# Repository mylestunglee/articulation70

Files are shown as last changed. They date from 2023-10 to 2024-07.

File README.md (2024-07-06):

# articulation70

The _articulation70_ keyboard is a successor to the [articulation80](https://github.com/mylestunglee/articulation80), with LEDs and a more personalised layout.

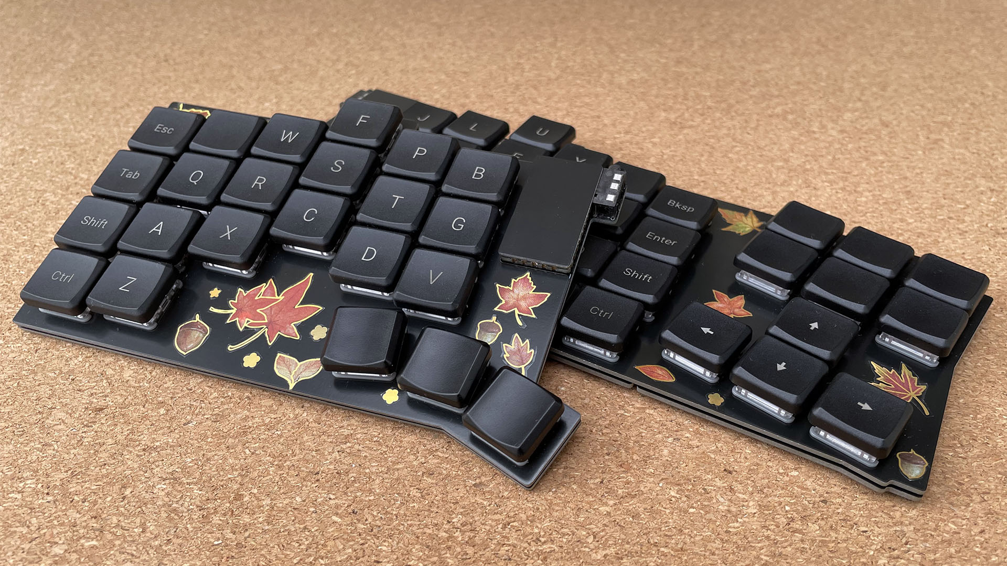
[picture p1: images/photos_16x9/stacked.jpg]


It features:
- Variable pinky stagger, supporting ±1 mm vertically offsetted soldering configurations.
- 3 × 6 main body, 3 thumb switches, 2 corner switches and 3 × 4 numpad layout.
- Kailh Choc V1 hot-swap support.
- A breakaway-able number pad.
- Serial or I2C connection between halves.
- Pro Micro-compatible controller support, however a micro-controller. with more pins are required to operate LEDs 2 and 3.
- 3 LEDs
- Reversible PCB to reduce manufacturing costs for hobby usage.

## KiCad plugins

This repo comes included with two plugins. To install these plugins, copy the directories in `plugins` into your _Plugins Directory_, which is found by _Tools → External Plugins → Open Plugins Directory_ in the PCB Editor.

### Split intersecting traces

When joining traces from rotated switches, it can be difficult to connect traces from two angles to form a aesthetic curve. This plugins splits two selected intersecting traces into four traces.

An example of use:

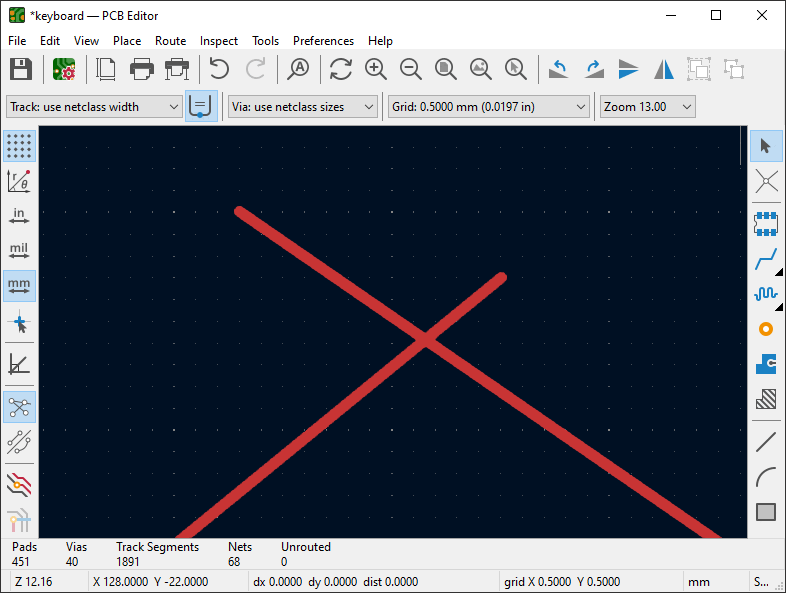
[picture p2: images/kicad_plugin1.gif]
KiCad plugin 1 animation


### Total trace length

Why not?

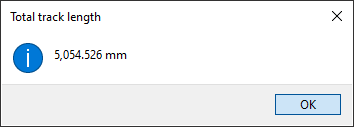
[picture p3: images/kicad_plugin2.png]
KiCad plugin 1


## Build Instructions

This build is very similar to many hobby keyboards. Please refer to the instructions for  [articulation80](https://github.com/mylestunglee/articulation80). You will need a soldering iron.

#### Which jumpers do I need to solder?

If using serial, then solder J1, and J4. If using I2C, then solder J2, J3 and J4. Solder on the back of each respective half.

### Build Parts

I would recommend substituting for cheaper or easier to source components when possible.

| Component | Quantity | MPN | Purchase Link | Remarks |
|:-|:-|:-|:-|:-|
| PCB | 2 |
| Left switch plate | 1
| Right switch plate | 1
| Micro-controller plate | 2
| Micro-controller | 2 | Elite-C | [Link](https://mechboards.co.uk/products/elite-c-v4)
| Through-hole TRRS jack | 2 | PJ-320A | [Link](https://mechboards.co.uk/products/trrs-jacks?variant=40330077241549)
| TRRS cable | 1 | | [Link](https://mou.sr/3QC5ykN) | Also called a 4-pin 3.5mm audio auxiliary cable |
| Reset button | 2 | PTS526 SM15 SMTR2 LFS | [Link](https://mou.sr/3tXtsOQ) | Different button operating force are possible
| LED | 3 | HLMP-1401 | [Link](https://mou.sr/45Zy9Vw) | Any T1 size
| 150Ω Resistor  | 3 | RC1206FR-07150RL | [Link](https://mou.sr/3QEyQzo) | Optional, for LEDs
| 4.7kΩ Resistor  | 2 | RC1206FR-104K7L | [Link](https://mou.sr/46XoOPE) | Optional, for I2C connection
| SMD Diode | 70* | 1N4148W-TP | [Link](https://mou.sr/3D01KSP) | Any SOD-123 size |
| Hot swap micro-controller sockets | 5 | 315-43-112-41-003000 | [Link](https://mou.sr/3QfEIO2) | Recommended
| Hot swap pins | 52 | 3320-0-00-15-00-00-03-0 | [Link](https://mou.sr/3tYd80f) | Recommended |
| Rubber feet | 12** | SJ-5302 CLEAR | [Link](https://mou.sr/3QFq1oL)
| Hot swap key sockets | 70* | CPG135001S30 | [Link](https://mechboards.co.uk/products/kailh-choc-hotswap-sockets)
| Key Switch | 70* | CPG135001 | [Link](https://www.aliexpress.com/item/1005005446722280.html)
| Key Cap | 70* | | | Ideally different key caps for thumbs |
| Stickers | 1 | | [Link](https://www.aliexpress.com/item/1005005222836654.html) | Optional

*Adjust for number of keys desired.

**Adjust for number of numpads.

## How to order PCBs and plates

I ordered from JLCPCB, however there are many other manufacturers. Take a look at [PCBShopper](https://pcbshopper.com/).

For the PCBs, I used:
- Base material: FR-4
- PCB thickness: 1.6 mm
- PCB colour: black
- Surface finish: LeadFree HASL
- Remove order number: Yes

For the switch plates, I used:
- Base material: FR-4
- PCB thickness: 1.2 mm
- PCB colour: black
- Surface finish: HASL (with lead) because the unleaded option greatly increases cost and the plates do not have any pads.
- Remove order number: Yes

For the controller plates, I used:
- Base material: FR-4
- PCB thickness: 1.2 mm
- PCB colour: black
- Surface finish: HASL (with lead)
- Remove order number: Yes

## How to adjust the layout

This was tested on installation of FreeCad 0.20.2, Python 3.11.6 and KiCad 7.0.6.

1. First, open `layout.FCStd` with FreeCad and open _Constants_ under the model tree view. You should see a spreadsheet of parameters.

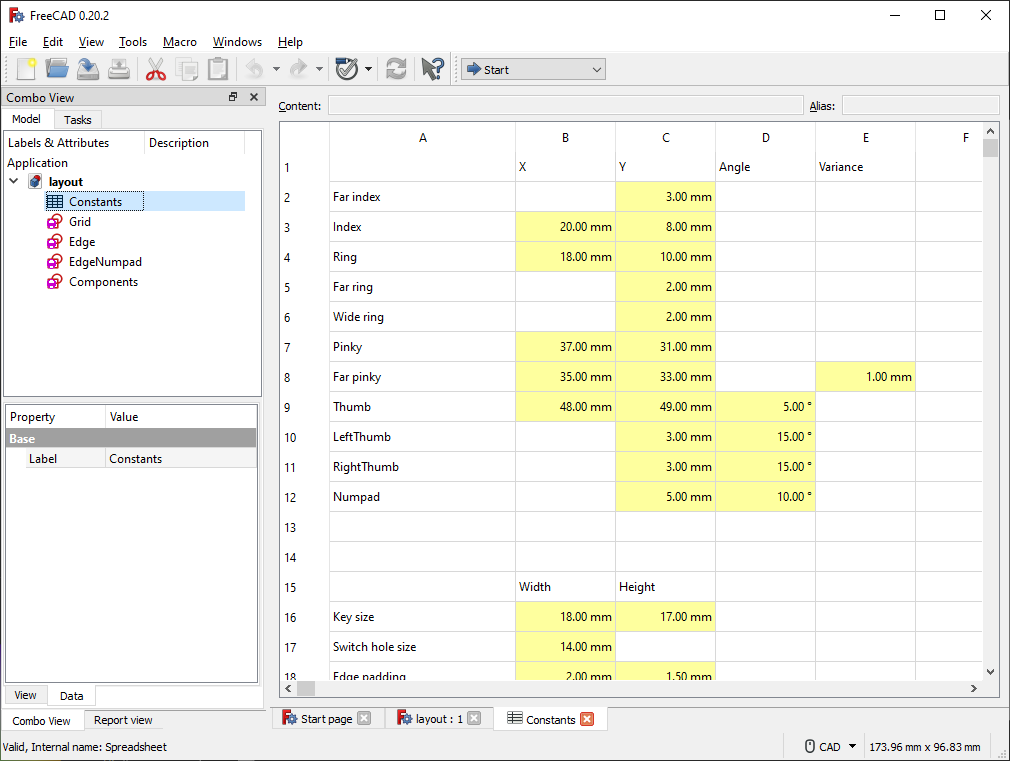
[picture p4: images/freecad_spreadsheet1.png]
FreeCad spreadsheet 1

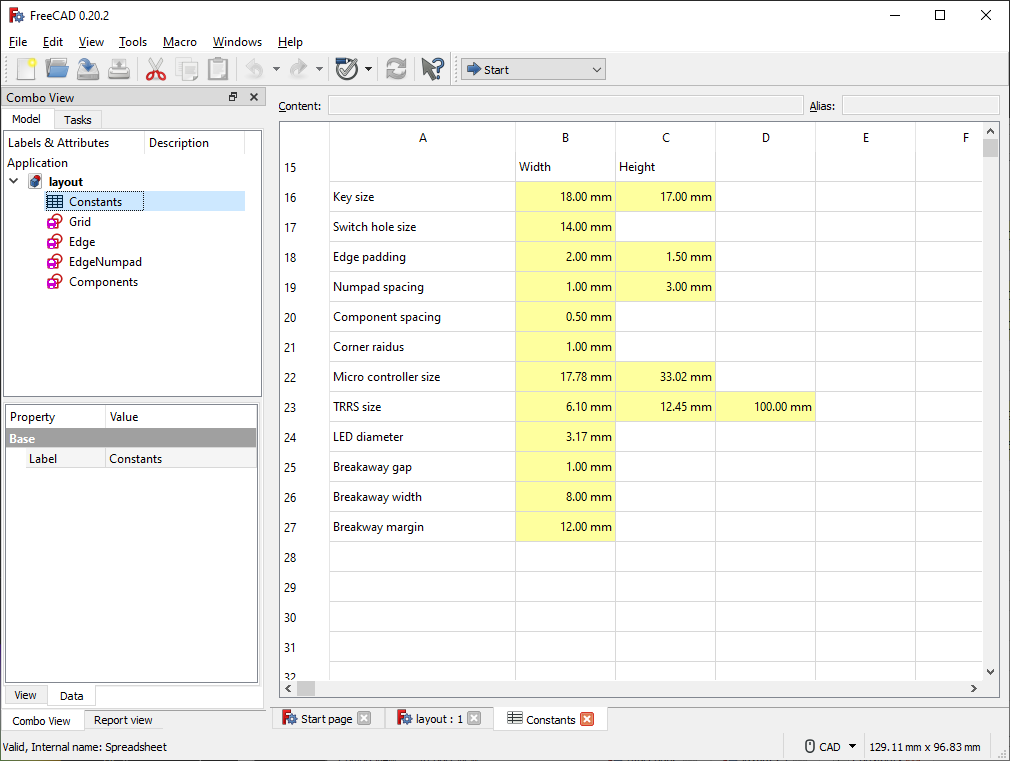
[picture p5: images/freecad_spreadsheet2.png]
FreeCad spreadsheet 2


2. Change values as necessary. If the values change too much from their intended range, then the sketch (as shown in the next step) may become broken.
3. Click on one of the sketches in the model tree view. Verify the layout shown is correct.

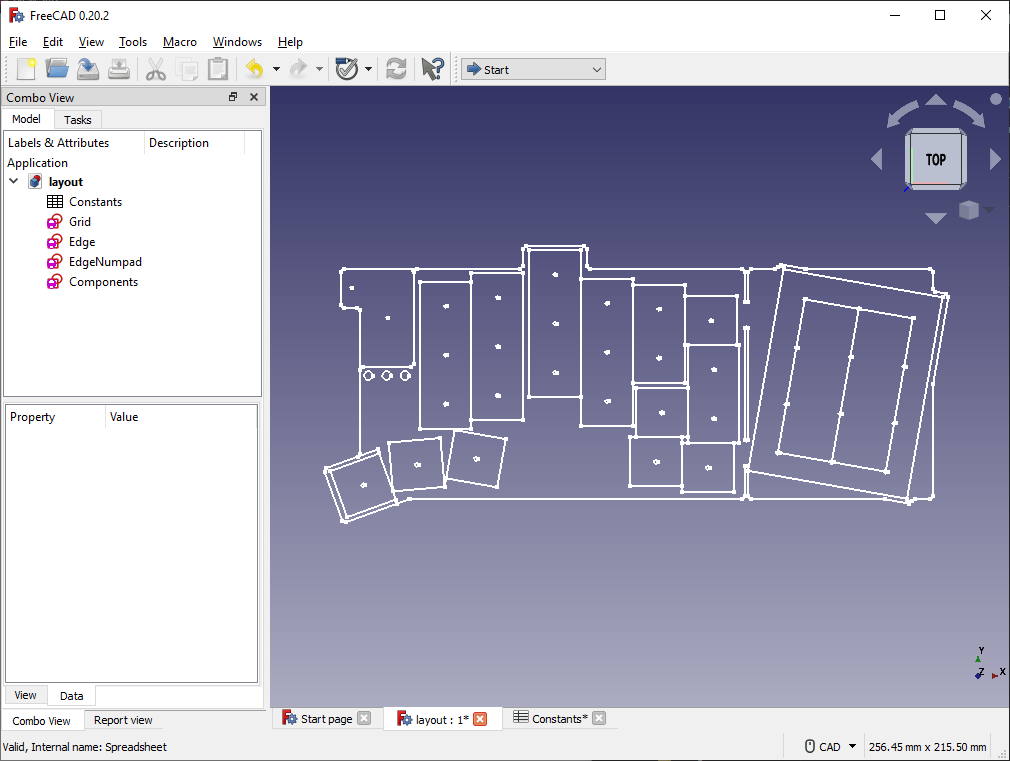
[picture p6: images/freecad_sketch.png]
FreeCad sketch


4. Export the layout to a file by coping the contents of `scripts/export_geometry.py` into FreeCad's Python console. The console is accessible by _View → Panel → Python console_. If you get a permission error, change `geometry.txt` to an absolute path within the repo. You should get a number, which reports the bytes written to `geometry.txt`.

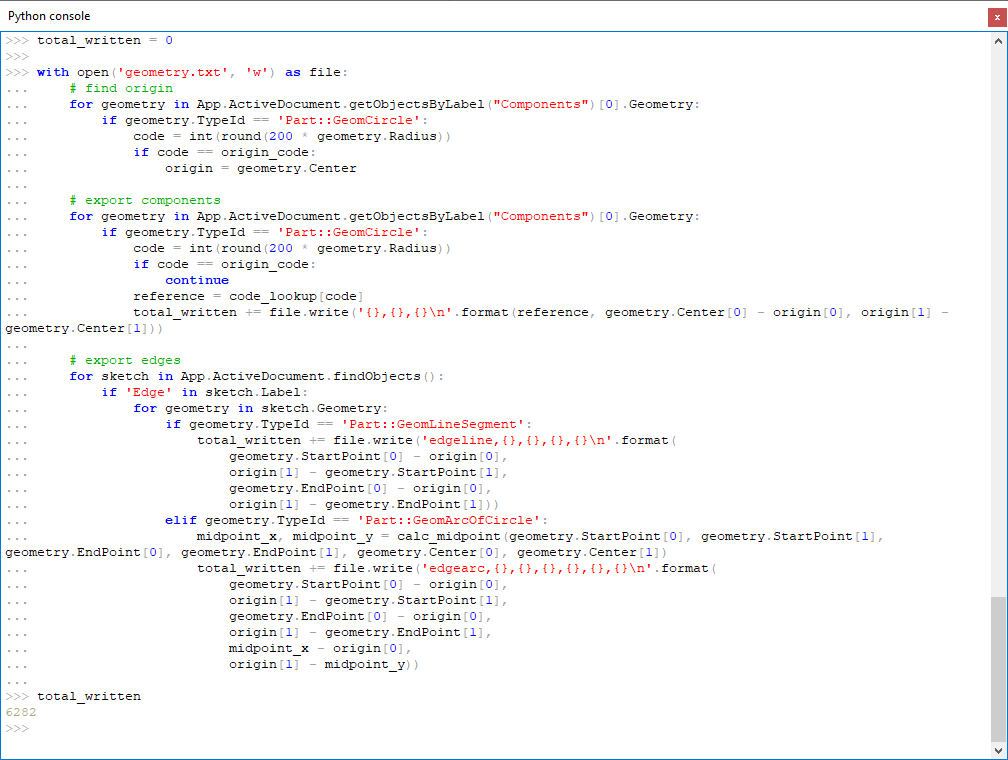
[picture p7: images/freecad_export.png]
FreeCad export


5. Update the PCB by running the following scripts:

```
python scripts/update_geometry.py pcb/keyboard.kicad_pcb geometry.txt
python scripts/update_geometry.py left_plate/plate.kicad_pcb geometry.txt
python scripts/update_geometry.py right_plate/plate.kicad_pcb geometry.txt
```

For now, I will run the first script. Update the PCB files for the plates if desired.

6. Clean-up residual graphic objects on the `Edge.Cuts` layer. The script deletes all previous edges and plots edges in the `Edge` and `EdgeNumpad` sketch, which includes construction lines that should not be included in the `Edge.Cuts` layer. The script also positions footprints according to the `Components` sketch. The script will output some text because some components' positions are not specified by the layout, such as the resistors.

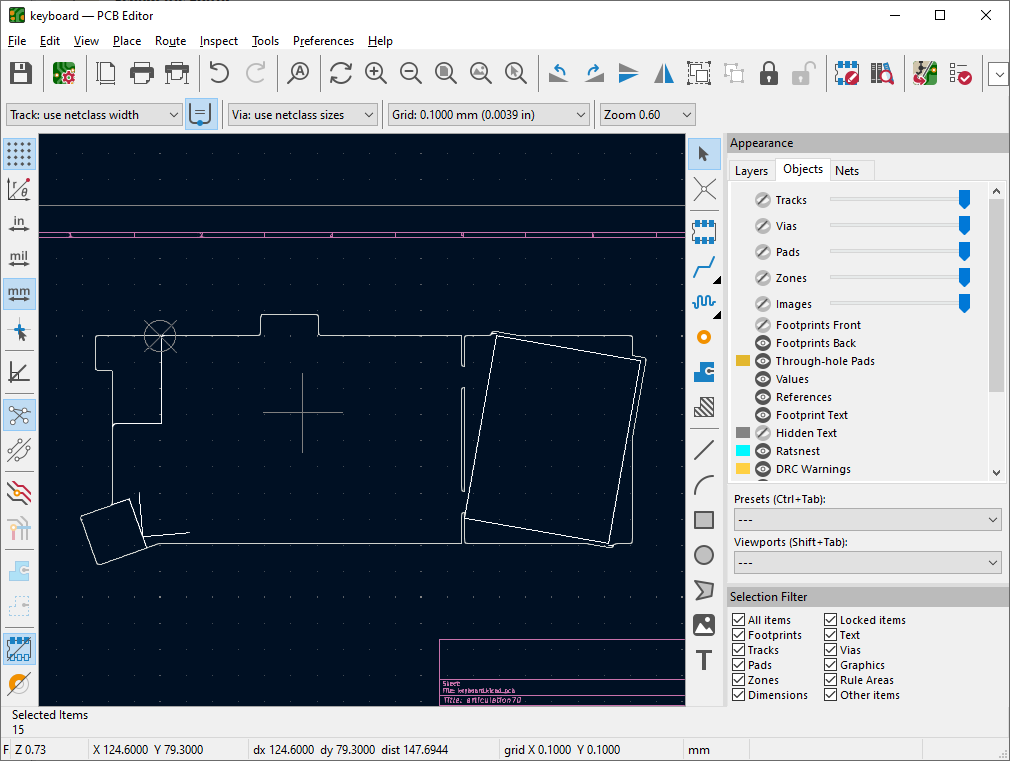
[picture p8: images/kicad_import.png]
KiCad import


7. Update traces and refill copper zones. Unfortunately this step takes the longest. Make sure to thoroughly check PCB.

The PCB is ready!

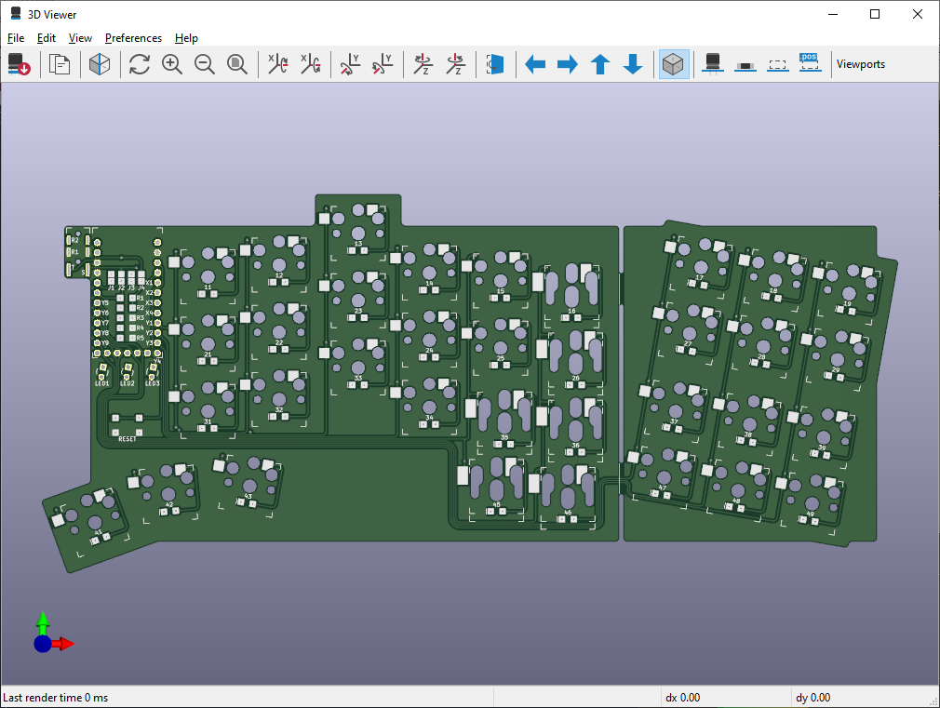
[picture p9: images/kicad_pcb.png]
KiCad PCB


## Firmware

I used [QMK](https://qmk.fm/) program the controllers. To use the same setup as me, copy the contents of `qmk` directory into your installation of `qmk_firmware/keyboards`. Flash the left and right controllers with the respective commands:
```
qmk flash -kb articulation70 -km default -bl dfu-split-left
qmk flash -kb articulation70 -km default -bl dfu-split-right
```
These commands assume the usage of Elite-C's.

If you want to upgrade the toolchain, you can do so at your own risk:
```
pacboy update avr-gcc:x
```

## Additional documentation

```
scripts/corner_switch_pad_geometry.py
scripts/curved_switch_pad_geometry.py
```

These switches generate the geometry for curved pads featured in the switch footprints. The curved shape comes from the rectangular pad subtracted by the clearance of the centre switch drill hole. KiCad supports polygons in pads, but it is not very easy to use. These scripts makes the design of these footprints a bit easier.

## Gallery

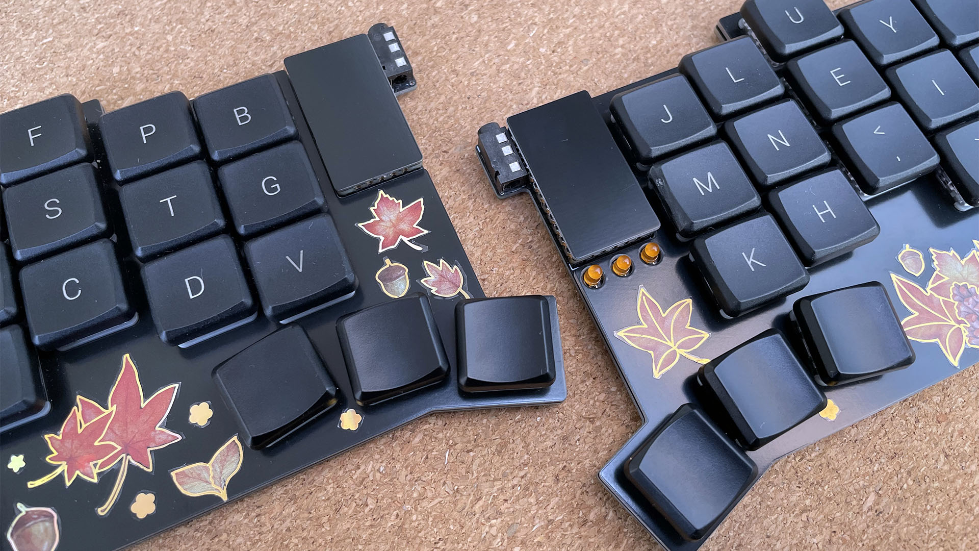
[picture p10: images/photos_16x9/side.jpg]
Photo both

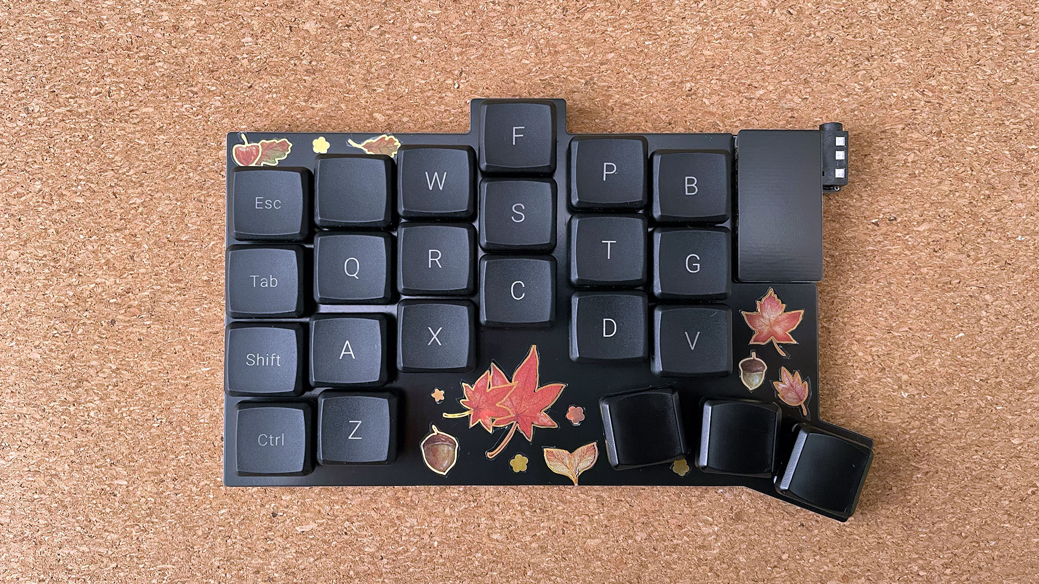
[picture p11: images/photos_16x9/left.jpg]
Photo left

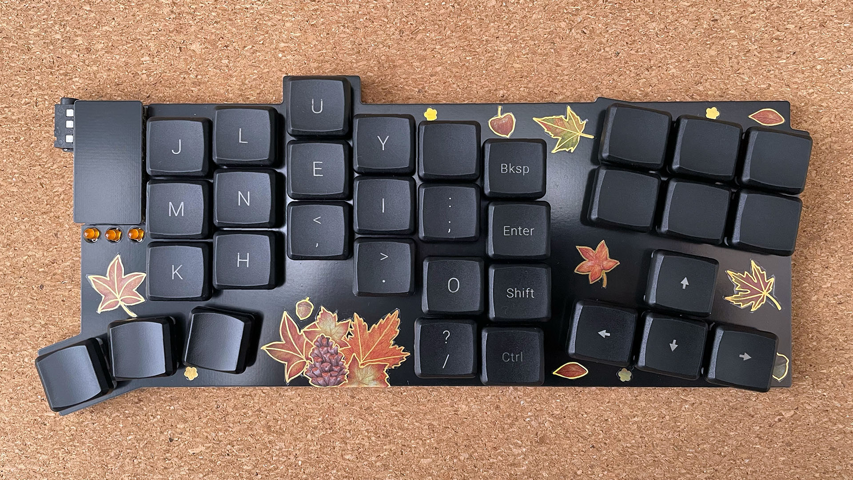
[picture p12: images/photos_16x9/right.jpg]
Photo right


More images can be found [here](https://github.com/mylestunglee/articulation70/tree/master/images).

## Future Considerations

There are a few improvements that can be made:

- Adding a pattern to improve aesthetics on the plates.
- Adding solder mask expansion on pads and pins.
- Re-route `ROW4` trace.
- Support LED placement in top-right.
- Improve LED brightness as they are too dim.
- Support both micro-controllers mounted face down.
- Strive to continually improve layout. The key columns are perpendicular to the fingers. This does not effectively utilise the flexibility of the hand.

## Credit

Thanks to:
- [KBD.news](https://kbd.news/) for inspiration.
- `sevmyer` for the [open-source KiCad teardrop plugin](https://github.com/sevmeyer/kicad-arc-teardrops) which was very helpful given many KiCad teardrop plugins were for Kicad 6.
- The QMK community on Discord for their helpful explanations.
- Various open source keyboards for guidance, but not limited to: [KLOTZ](https://github.com/GEIGEIGEIST/KLOTZ), [Corne](https://github.com/foostan/crkbd) and [Breeze](https://www.afternoonlabs.com/breeze/).

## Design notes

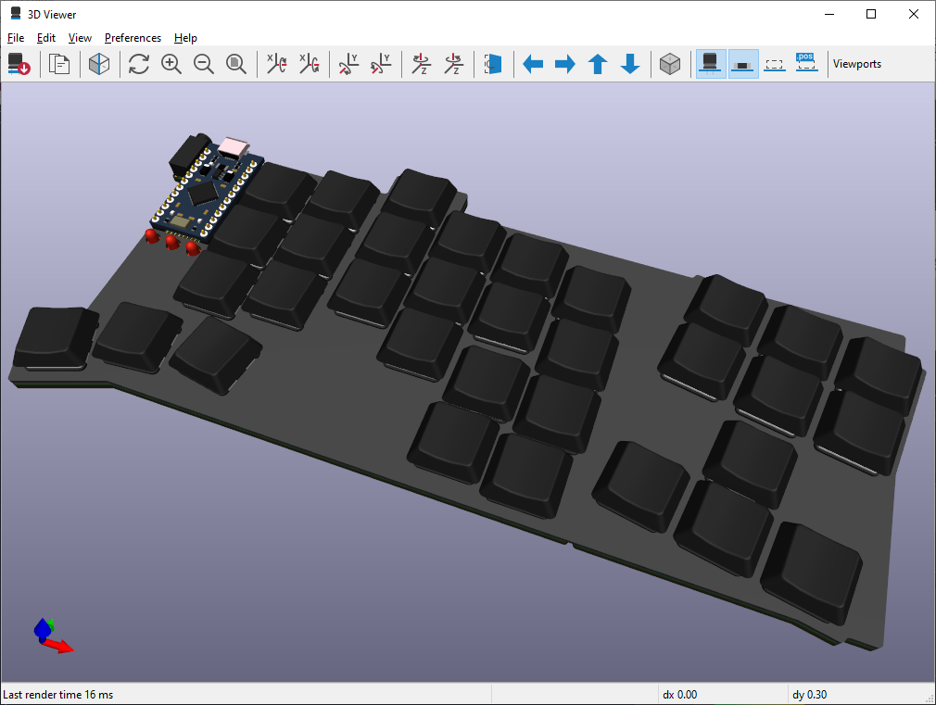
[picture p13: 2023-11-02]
images/kicad_right.png

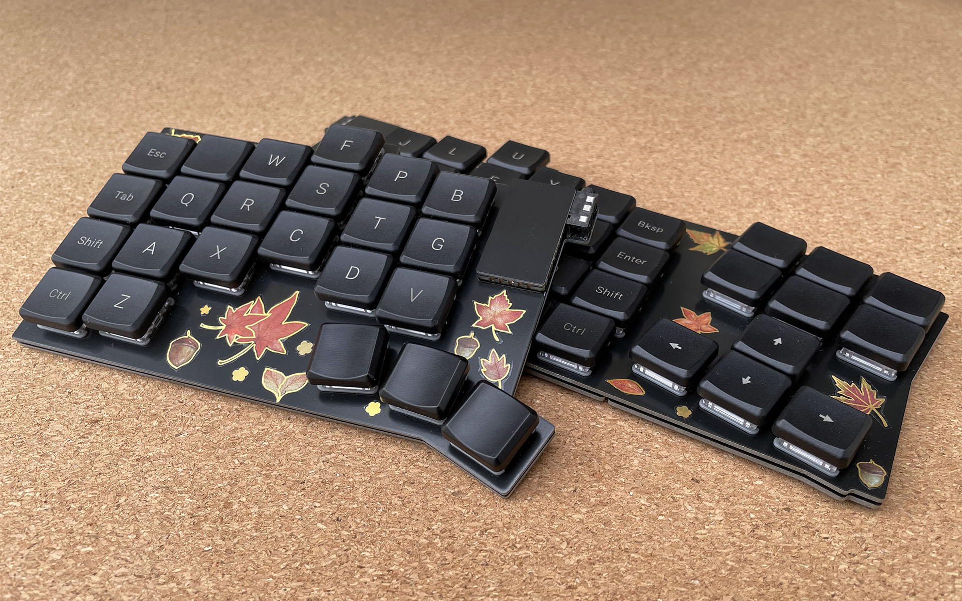
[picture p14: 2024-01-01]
images/photos_16x10/stacked.jpg

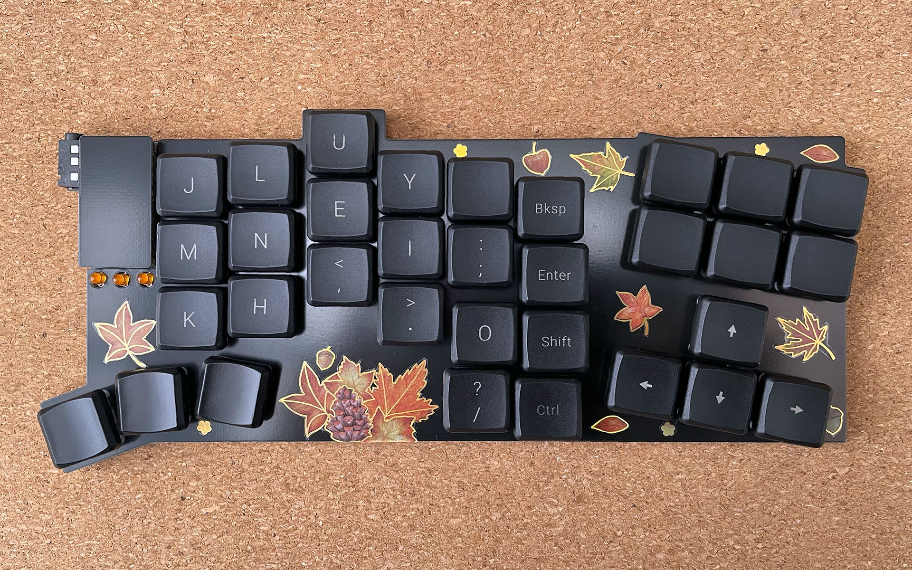
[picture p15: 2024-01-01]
images/photos_16x10/right.jpg

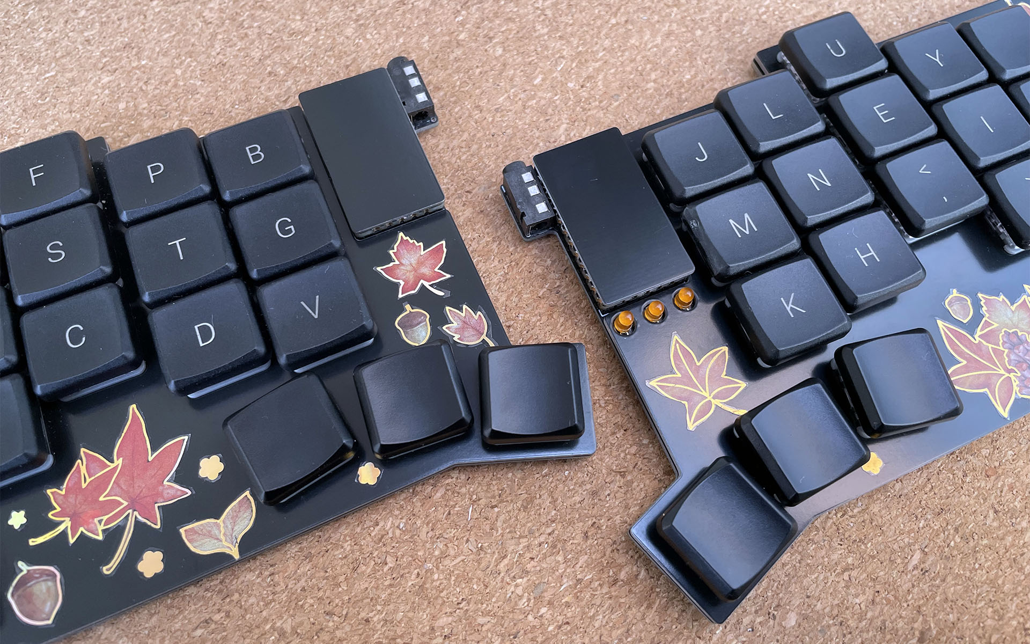
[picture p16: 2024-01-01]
images/photos_16x10/side.jpg

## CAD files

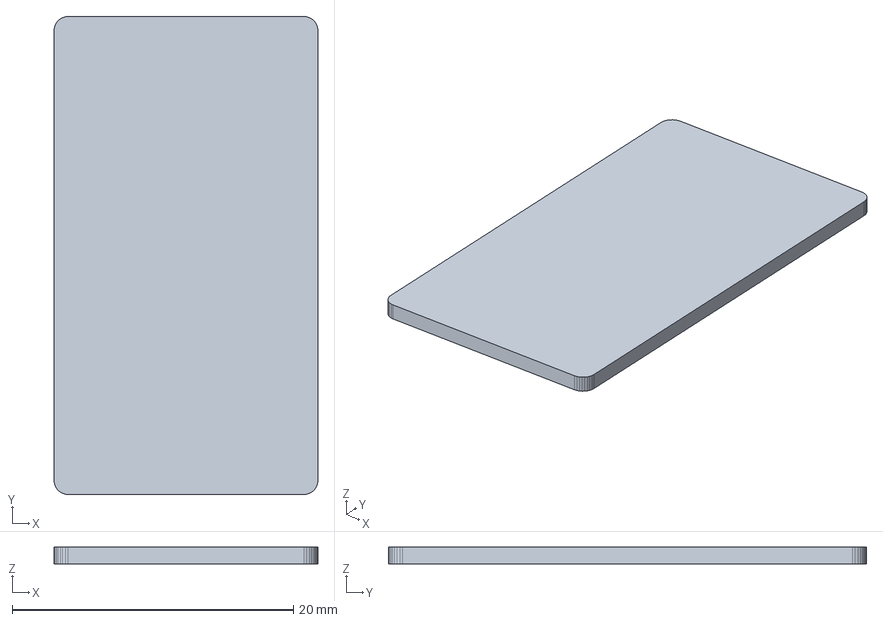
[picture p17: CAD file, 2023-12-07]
pcb/controller-plate.step
18.8 x 34.0 x 1.18 mm

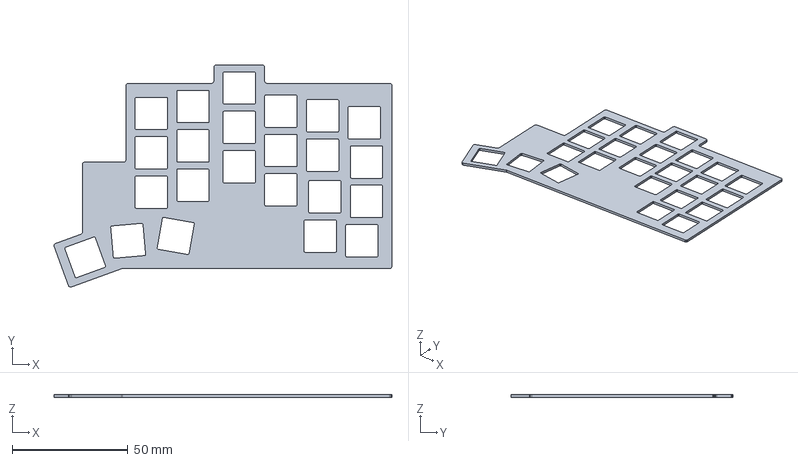
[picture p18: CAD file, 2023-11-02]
pcb/left-plate.step
146.0 x 96.0 x 1.20 mm

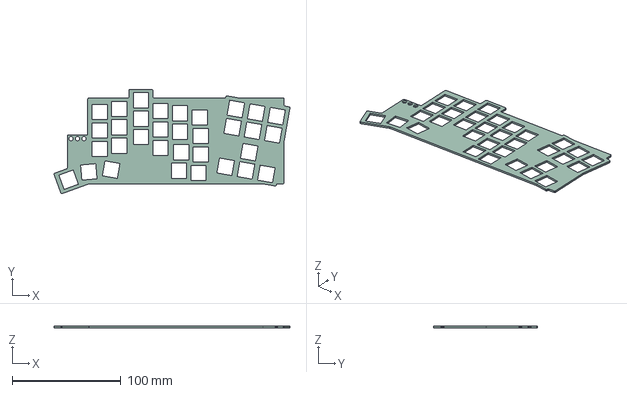
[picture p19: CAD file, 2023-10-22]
pcb/right-keyboard.step
217.2 x 96.0 x 1.60 mm

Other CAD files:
layout.FCStd

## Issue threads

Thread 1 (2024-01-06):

Key layout to print and try out?

mejobloggs, 2024-01-06:
Hello, is there a key layout image available for printing? Or a way to generate it via freecad etc?

I want to see how it feels with my hands.

I also wanted to leave a comment saying how awesome this keyboard looks. You've done amazing work and I'm very impressed by the details of instructions and adjustable layout in freecad and all the thought you've put into this. Very cool

mylestunglee, 2024-01-07:
Hello @mejobloggs ,

Thank you for the kind words. There are a couple of ways to do this, however I think by exporting the layers in FreeCad as an SVG, then printing this should be a good approximation. I've attached a PDF with the default layout. The FreeCad layout does not show the pinky stagger variation but it is fixed to ±1mm but it is up to you if you want to use it. I suppose there should be a way via KiCad, but I would guess it would be more tedious. Hope this helps.

[layout.pdf](https://github.com/mylestunglee/articulation70/files/13851789/layout.pdf)

mejobloggs, 2024-01-07:
Thanks very much 👍

Closed 2024-01-07.

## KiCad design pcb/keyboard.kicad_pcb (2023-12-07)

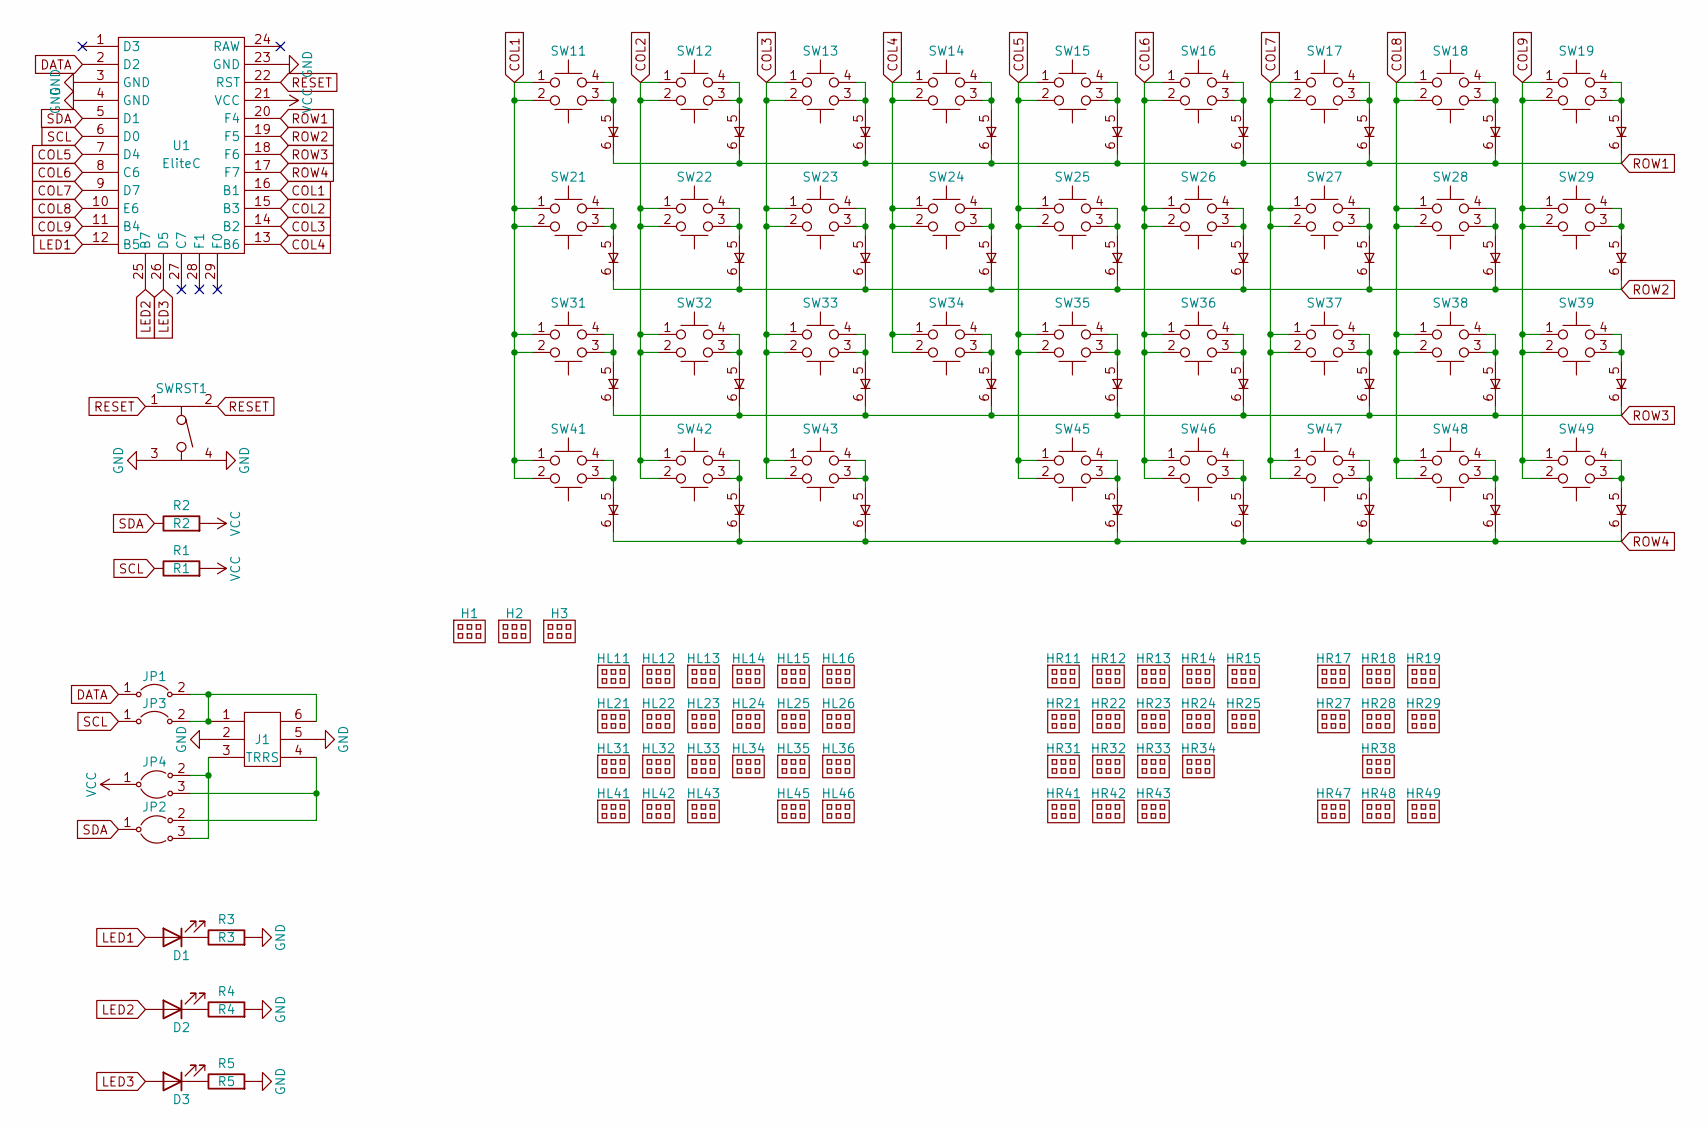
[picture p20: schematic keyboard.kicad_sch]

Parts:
D1: LED1; HLMP-1401
D2: LED2; HLMP-1401
D3: LED3; HLMP-1401
H1: H1; RightPlate
H2: H2; LeftPlate
H3: H2; ControllerPlate
HL11, HL12, HL13, HL14, HL15, HL21, HL22, HL23, HL24, HL25, HL31, HL32, HL33, HL34, HL41, HL42, HL43: Switch3DLeft
HL16, HL26, HL35, HL36, HL45, HL46: SwitchDoubleLeft
HR11, HR12, HR13, HR14, HR15, HR17, HR18, HR19, HR21, HR22, HR23, HR24, HR25, HR27, HR28, HR29, HR31, HR32, HR33, HR34, HR38, HR41, HR42, HR43, HR47, HR48, HR49: Switch3DRight
J1: TRRS; PJ-320A
JP1: J1; Jumper
JP2: J2; JumperSplit
JP3: J3; Jumper
JP4: J4; JumperSplit
R1: R1; SDR18
R2: R2; SDR18
R3: R3; SDR18
R4: R4; SDR18
R5: R5; SDR18
SW11: 11; Switch
SW12: 12; Switch
SW13: 13; Switch
SW14: 14; Switch
SW15: 15; Switch
SW16: 16; SwitchDoubleRight
SW17: 17; Switch
SW18: 18; Switch
SW19: 19; Switch
SW21: 21; Switch
SW22: 22; Switch
SW23: 23; Switch
SW24: 24; Switch
SW25: 25; Switch
SW26: 26; SwitchDoubleRight
SW27: 27; Switch
SW28: 28; Switch
SW29: 29; Switch
SW31: 31; Switch
SW32: 32; Switch
SW33: 33; Switch
SW34: 34; Switch
SW35: 35; SwitchDoubleRight
SW36: 36; SwitchDoubleRight
SW37: 37; Switch
SW38: 38; Switch
SW39: 39; Switch
SW41: 41; Switch
SW42: 42; Switch
SW43: 43; Switch
SW45: 45; SwitchDoubleRight
SW46: 46; SwitchDoubleRight
SW47: 47; Switch
SW48: 48; Switch
SW49: 49; Switch
SWRST1: PTS526
U1: EliteC

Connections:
COL1: SW11.1, SW11.2, SW21.1, SW21.2, SW31.1, SW31.2, SW41.1, SW41.2, U1.16 (B1)
COL2: SW12.1, SW12.2, SW22.1, SW22.2, SW32.1, SW32.2, SW42.1, SW42.2, U1.15 (B3)
COL3: SW13.1, SW13.2, SW23.1, SW23.2, SW33.1, SW33.2, SW43.1, SW43.2, U1.14 (B2)
COL4: SW14.1, SW14.2, SW24.1, SW24.2, SW34.1, SW34.2, U1.13 (B6)
COL5: SW15.1, SW15.2, SW25.1, SW25.2, SW35.1, SW35.2, SW45.1, SW45.2, U1.7 (D4)
COL6: SW16.1, SW16.2, SW26.1, SW26.2, SW36.1, SW36.2, SW46.1, SW46.2, U1.8 (C6)
COL7: SW17.1, SW17.2, SW27.1, SW27.2, SW37.1, SW37.2, SW47.1, SW47.2, U1.9 (D7)
COL8: SW18.1, SW18.2, SW28.1, SW28.2, SW38.1, SW38.2, SW48.1, SW48.2, U1.10 (E6)
COL9: SW19.1, SW19.2, SW29.1, SW29.2, SW39.1, SW39.2, SW49.1, SW49.2, U1.11 (B4)
DATA: JP1.1, U1.2 (D2)
GND: J1.2, J1.5, R3.2, R4.2, R5.2, SWRST1.3, SWRST1.4, U1.3 (GND), U1.4 (GND), U1.23 (GND)
LED1: D1.2 (A), U1.12 (B5)
LED2: D2.2 (A), U1.25 (B7)
LED3: D3.2 (A), U1.26 (D5)
unnamed: D1.1 (K), R3.1
unnamed: D2.1 (K), R4.1
unnamed: D3.1 (K), R5.1
unnamed: J1.1, J1.6, JP1.2, JP3.2
unnamed: J1.3, JP2.3, JP4.2
unnamed: J1.4, JP2.2, JP4.3
unnamed: SW11.3, SW11.4, SW11.5
unnamed: SW12.3, SW12.4, SW12.5
unnamed: SW13.3, SW13.4, SW13.5
unnamed: SW14.3, SW14.4, SW14.5
unnamed: SW15.3, SW15.4, SW15.5
unnamed: SW16.3, SW16.4, SW16.5
unnamed: SW17.3, SW17.4, SW17.5
unnamed: SW18.3, SW18.4, SW18.5
unnamed: SW19.3, SW19.4, SW19.5
unnamed: SW21.3, SW21.4, SW21.5
unnamed: SW22.3, SW22.4, SW22.5
unnamed: SW23.3, SW23.4, SW23.5
unnamed: SW24.3, SW24.4, SW24.5
unnamed: SW25.3, SW25.4, SW25.5
unnamed: SW26.3, SW26.4, SW26.5
unnamed: SW27.3, SW27.4, SW27.5
unnamed: SW28.3, SW28.4, SW28.5
unnamed: SW29.3, SW29.4, SW29.5
unnamed: SW31.3, SW31.4, SW31.5
unnamed: SW32.3, SW32.4, SW32.5
unnamed: SW33.3, SW33.4, SW33.5
unnamed: SW34.3, SW34.4, SW34.5
unnamed: SW35.3, SW35.4, SW35.5
unnamed: SW36.3, SW36.4, SW36.5
unnamed: SW37.3, SW37.4, SW37.5
unnamed: SW38.3, SW38.4, SW38.5
unnamed: SW39.3, SW39.4, SW39.5
unnamed: SW41.3, SW41.4, SW41.5
unnamed: SW42.3, SW42.4, SW42.5
unnamed: SW43.3, SW43.4, SW43.5
unnamed: SW45.3, SW45.4, SW45.5
unnamed: SW46.3, SW46.4, SW46.5
unnamed: SW47.3, SW47.4, SW47.5
unnamed: SW48.3, SW48.4, SW48.5
unnamed: SW49.3, SW49.4, SW49.5
RESET: SWRST1.1, SWRST1.2, U1.22 (RST)
ROW1: SW11.6, SW12.6, SW13.6, SW14.6, SW15.6, SW16.6, SW17.6, SW18.6, SW19.6, U1.20 (F4)
ROW2: SW21.6, SW22.6, SW23.6, SW24.6, SW25.6, SW26.6, SW27.6, SW28.6, SW29.6, U1.19 (F5)
ROW3: SW31.6, SW32.6, SW33.6, SW34.6, SW35.6, SW36.6, SW37.6, SW38.6, SW39.6, U1.18 (F6)
ROW4: SW41.6, SW42.6, SW43.6, SW45.6, SW46.6, SW47.6, SW48.6, SW49.6, U1.17 (F7)
SCL: JP3.1, R1.1, U1.6 (D0)
SDA: JP2.1, R2.1, U1.5 (D1)
VCC: JP4.1, R1.2, R2.2, U1.21 (VCC)

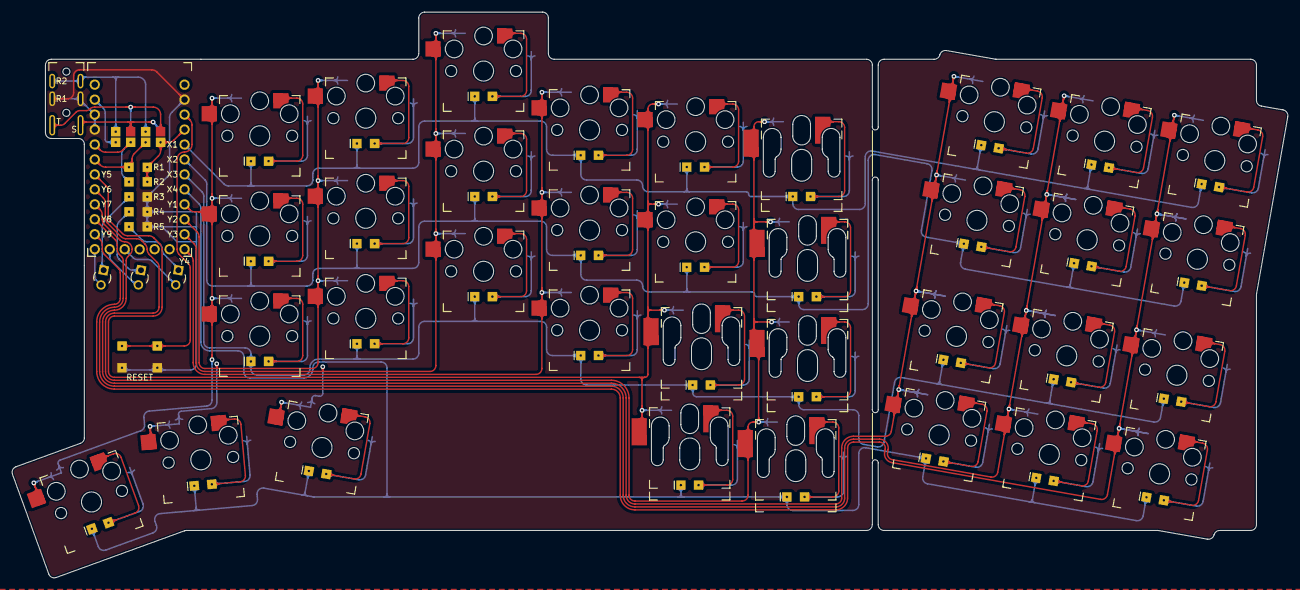
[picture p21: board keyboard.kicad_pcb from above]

Board: 2 copper layers, 216.6 x 96.0 mm, 103 parts (0 on the bottom side), 63 nets.

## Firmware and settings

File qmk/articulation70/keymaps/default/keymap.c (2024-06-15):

#include QMK_KEYBOARD_H
#include "keymap_uk.h"

enum Layers {
    LAYER_BASE,
    LAYER_NUMPAD,
    LAYER_GAME,
    LAYER_LOWER,
    LAYER_UPPER,
    LAYER_ADJUST,
    LAYER_STATUS
};

#define KC_TGNU TG(LAYER_NUMPAD)
#define KC_TGGA TG(LAYER_GAME)
#define KC_MOST MO(LAYER_STATUS)
#define LED1 B5
#define LED2 B7
#define LED3 D5
#define LED_BLINK_DURATION 1000

const uint16_t PROGMEM keymaps[][MATRIX_ROWS][MATRIX_COLS] = {
    [LAYER_BASE] = LAYOUT_split(
        KC_ESC  , KC_F4   , KC_L    , KC_D    , KC_W    , KC_Q              ,           KC_QUOT , KC_F    , KC_O    , KC_U    , KC_PSCR , KC_BSPC , KC_INS  , KC_HOME , KC_PGUP ,
        KC_TAB  , KC_B    , KC_R    , KC_T    , KC_S    , KC_G              ,           KC_Y    , KC_H    , KC_A    , KC_E    , KC_J    , KC_ENT  , KC_DEL  , KC_END  , KC_PGDN ,
        KC_LSFT , KC_N    , KC_X    , KC_M    , KC_C    , KC_V              ,           KC_K    , KC_P    , KC_COMM , KC_DOT  , KC_I    , KC_RSFT           , KC_UP   ,
        KC_LCTL , KC_Z    ,                     KC_LALT , KC_BSPC , TL_LOWR , TL_UPPR , KC_SPC  , KC_RGUI                     , KC_SLSH , KC_RCTL , KC_LEFT , KC_DOWN , KC_RGHT
    ),
    [LAYER_NUMPAD] = LAYOUT_split(
        _______ , _______ , _______ , _______ , _______ , _______           ,           KC_PSLS , KC_P7   , KC_P8   , KC_P9   , KC_PMNS , _______ , _______ , _______ , _______ ,
        _______ , _______ , _______ , _______ , _______ , _______           ,           KC_PAST , KC_P4   , KC_P5   , KC_P6   , KC_PPLS , KC_PENT , _______ , _______ , _______ ,
        _______ , _______ , _______ , _______ , _______ , _______           ,           KC_NO   , KC_P1   , KC_P2   , KC_P3   , KC_P0   , _______           , _______ ,
        _______ , _______ ,                     _______ , _______ , _______ , _______ , _______ , _______                     , KC_PDOT , _______ , _______ , _______ , _______
    ),
    [LAYER_GAME] = LAYOUT_split(
        _______ , _______ , _______ , _______ , _______ , _______           ,           KC_R    , KC_E    , KC_X    , KC_Q    , KC_ESC  , _______ , _______ , _______ , _______ ,
        _______ , _______ , _______ , _______ , _______ , _______           ,           KC_F    , KC_A    , KC_W    , KC_D    , KC_TAB  , _______ , _______ , _______ , _______ ,
        _______ , _______ , _______ , _______ , _______ , _______           ,           KC_V    , KC_C    , KC_S    , KC_Z    , KC_LSFT , KC_LALT           , _______ ,
        _______ , _______ ,                     _______ , _______ , _______ , _______ , _______ , _______                     , KC_LCTL , UK_BSLS , _______ , _______ , _______
    ),
    [LAYER_LOWER] = LAYOUT_split(
        KC_VOLD , KC_VOLU , UK_HASH , KC_QUOT , KC_SCLN , KC_MOST           ,           KC_NUM  , KC_AMPR , KC_ASTR , KC_LPRN , KC_NO   , _______ , _______ , _______ , _______ ,
        _______ , KC_GRV  , KC_LPRN , KC_RPRN , KC_MINS , KC_MOST           ,           KC_CAPS , KC_DLR  , KC_PERC , KC_CIRC , KC_RPRN , _______ , _______ , _______ , _______ ,
        _______ , KC_EQL  , KC_LCBR , KC_RCBR , KC_NO   , KC_MOST           ,           KC_SCRL , KC_EXLM , UK_DQUO , UK_PND  , KC_NO   , _______           , _______ ,
        _______ , UK_BSLS ,                     _______ , _______ , _______ , _______ , _______ , _______                     , KC_NO   , _______ , _______ , _______ , _______
    ),
    [LAYER_UPPER] = LAYOUT_split(
        KC_VOLD , KC_VOLU , UK_TILD , UK_AT   , KC_COLN , KC_MOST           ,           KC_NUM  , KC_7    , KC_8    , KC_9    , KC_MINS , KC_TGNU , _______ , _______ , _______ ,
        _______ , UK_NOT  , KC_LBRC , KC_RBRC , KC_UNDS , KC_MOST           ,           KC_CAPS , KC_4    , KC_5    , KC_6    , KC_PLUS , KC_PENT , _______ , _______ , _______ ,
        _______ , KC_PLUS , KC_LCBR , KC_RCBR , KC_NO   , KC_MOST           ,           KC_SCRL , KC_1    , KC_2    , KC_3    , KC_0    , _______           , _______ ,
        _______ , UK_PIPE ,                     _______ , _______ , _______ , _______ , _______ , _______                     , KC_DOT  , _______ , _______ , _______ , _______
    ),
    [LAYER_ADJUST] = LAYOUT_split(
        KC_TGGA , KC_NO   , KC_NO   , KC_NO   , KC_NO   , KC_MOST           ,           KC_NUM  , KC_F9   , KC_F10  , KC_F11  , KC_F12  , _______ , _______ , _______ , _______ ,
        _______ , KC_NO   , KC_NO   , KC_NO   , KC_NO   , KC_MOST           ,           KC_CAPS , KC_F5   , KC_F6   , KC_F7   , KC_F8   , _______ , _______ , _______ , _______ ,
        _______ , KC_NO   , KC_NO   , KC_NO   , KC_NO   , KC_MOST           ,           KC_SCRL , KC_F1   , KC_F2   , KC_F3   , KC_F4   , _______           , _______ ,
        _______ , KC_NO   ,                     _______ , _______ , _______ , _______ , _______ , _______                     , KC_NO   , _______ , _______ , _______ , _______
    ),
    [LAYER_STATUS] = LAYOUT_split(
        KC_TGGA , _______ , _______ , _______ , _______ , KC_MOST           ,           _______ , _______ , _______ , _______ , _______ , _______ , _______ , _______ , _______ ,
        _______ , _______ , _______ , _______ , _______ , KC_MOST           ,           _______ , _______ , _______ , _______ , _______ , _______ , _______ , _______ , _______ ,
        _______ , _______ , _______ , _______ , _______ , KC_MOST           ,           _______ , _______ , _______ , _______ , _______ , _______           , _______ ,
        _______ , _______ ,                     _______ , _______ , _______ , _______ , _______ , _______                     , _______ , _______ , _______ , _______ , _______
    )
};

bool g_blink_leds;
led_t g_led_state;
layer_state_t g_layer_state;

void update_leds(void) {
    if (g_blink_leds) {
        writePinHigh(LED1);
        writePinHigh(LED2);
        writePinHigh(LED3);
    } else {
        if (IS_LAYER_ON_STATE(layer_state, LAYER_STATUS)) {
            writePin(LED1, g_led_state.num_lock);
            writePin(LED2, g_led_state.caps_lock);
            writePin(LED3, g_led_state.scroll_lock);
        } else {
            writePin(LED1, IS_LAYER_ON_STATE(g_layer_state, LAYER_LOWER) || IS_LAYER_ON_STATE(g_layer_state, LAYER_ADJUST));
            writePin(LED2, IS_LAYER_ON_STATE(g_layer_state, LAYER_NUMPAD) || IS_LAYER_ON_STATE(g_layer_state, LAYER_UPPER) || IS_LAYER_ON_STATE(g_layer_state, LAYER_ADJUST));
            writePin(LED3, IS_LAYER_ON_STATE(g_layer_state, LAYER_GAME));
        }
    }
}

uint32_t after_led_blink(uint32_t trigger_time, void * args) {
    g_blink_leds = false;
    update_leds();
    return 0u;
}

void keyboard_post_init_user(void) {
    g_blink_leds = true;
    update_leds();
    defer_exec(LED_BLINK_DURATION, after_led_blink, NULL);
}

bool led_update_user(led_t led_state) {
    g_led_state = led_state;
    update_leds();
    return true;
}

layer_state_t layer_state_set_user(layer_state_t layer_state) {
    g_layer_state = layer_state;
    update_leds();
    return layer_state;
}

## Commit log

2023-10-02 add thumb cluster
    [layout.FCStd]
2023-10-03 adjust more
    [layout.FCStd]
2023-10-03 more adjustment for minimal curl
    [layout.FCStd]
2023-10-04 parameterise layout
    [layout.FCStd]
2023-10-05 add some edges
    [layout.FCStd]
2023-10-05 tight edges
    [layout.FCStd]
2023-10-05 parameterise thumb positions
    [layout.FCStd]
2023-10-05 add more edges
    [layout.FCStd]
2023-10-05 complete edge loop
    [layout.FCStd]
2023-10-06 remove numpad and add components to grid
    [layout.FCStd]
2023-10-06 add rotated numpad
    [layout.FCStd]
2023-10-06 remove LED suggestions
    [layout.FCStd]
2023-10-07 add component spacing
    [layout.FCStd]
2023-10-08 remove edges on snap off
    [layout.FCStd]
2023-10-08 create new pcb project with sample footprint
    [keyboard.kicad_pcb, keyboard.kicad_sch]
2023-10-08 add some footprints and adjust silkscreen
2023-10-08 rename footprint library
2023-10-08 update order of switches
    [layout.FCStd]
2023-10-08 add schematic
    [keyboard.kicad_sch]
2023-10-08 add LED and fix footprints references and positioning
    [keyboard.kicad_sch]
2023-10-08 remove excess switch in schematic
    [keyboard.kicad_sch]
2023-10-10 script porting of edges from FreeCad to KiCad
    [keyboard.kicad_pcb, layout.FCStd]
2023-10-11 script for footprint placement
    [keyboard.kicad_pcb, layout.FCStd]
2023-10-12 curve pad in switch footprint
    [keyboard.kicad_pcb]
2023-10-12 set switch number to silkscreen
    [keyboard.kicad_pcb, keyboard.kicad_sch]
2023-10-12 move TRRS to overhang and fix diode positioning
    [keyboard.kicad_pcb, layout.FCStd]
2023-10-13 make adjustments from iteration 11 printout and fix numpad switch positions
    [keyboard.kicad_pcb, layout.FCStd]
2023-10-13 adjust numpad x; add solder mask to jumper; add silkscreen line in snap off
    [keyboard.kicad_pcb, layout.FCStd]
2023-10-13 centre snap to switch pads and test traces
    [keyboard.kicad_pcb]
2023-10-14 experiment with switch label and diode positioning
    [keyboard.kicad_pcb]
2023-10-14 add lots of traces and remove solder mask from jumpers
    [keyboard.kicad_pcb, keyboard.kicad_sch]
2023-10-15 fix switch references
    [keyboard.kicad_pcb, keyboard.kicad_sch]
2023-10-15 add traces to numpad
    [keyboard.kicad_pcb]
2023-10-16 fix right thumb positioning
    [layout.FCStd]
2023-10-16 use polygon instead of drill offset for switch footprint
    [keyboard.kicad_pcb]
2023-10-16 collapse zero length lines in layout
    [layout.FCStd]
2023-10-16 adjust measurements from v12
    [layout.FCStd]
2023-10-17 correct traces with new layout
    [keyboard.kicad_pcb]
2023-10-17 add traces for thumb cluster
    [keyboard.kicad_pcb]
2023-10-17 add remaining bad traces
    [keyboard.kicad_pcb, keyboard.kicad_sch]
2023-10-18 improve tracing around microcontroller
    [keyboard.kicad_pcb, keyboard.kicad_sch]
2023-10-18 fix issues with footprints
2023-10-18 fix silkscreen around microcontroller
    [keyboard.kicad_pcb, keyboard.kicad_sch]
2023-10-18 move col7 trace around controller
    [keyboard.kicad_pcb]
2023-10-18 add ground area and fix teardrops
    [keyboard.kicad_pcb]
2023-10-19 remove fill at snap-off; fix teardrop; improve fill edge
    [keyboard.kicad_pcb]
2023-10-19 add teardrops to T junctions at traces
    [keyboard.kicad_pcb]
2023-10-19 add plate to 3D view
    [keyboard.kicad_pcb, keyboard.kicad_sch, left-keyboard.step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]
2023-10-19 change plate color; remove 3d models from ignored switches
    [keyboard.kicad_pcb, left-keyboard.step, right-keyboard.step]
2023-10-20 fix teardrop for reset button
    [keyboard.kicad_pcb]
2023-10-21 improve edges in layout
    [layout.FCStd]
2023-10-21 move graphical copper arcs to traces; use default teardrop size
    [keyboard.kicad_pcb, keyboard.kicad_sch]
2023-10-21 fix reference of LED and add project for right plate
    [plate.kicad_pcb, plate.kicad_sch, right-keyboard.step]
2023-10-21 add left plate; update hole footprints; update STEP files
    [left-keyboard.step, plate.kicad_pcb, plate.kicad_sch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]
2023-10-21 support 3d view of left plate
    [keyboard.kicad_pcb, keyboard.kicad_sch]
2023-10-22 change snap off thickness to 1.6mm for fab house
    [keyboard.kicad_pcb, layout.FCStd, left-keyboard.step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]
2023-10-22 hide back of LED by rotation; resistor after LED
    [keyboard.kicad_pcb, keyboard.kicad_sch]
2023-10-23 adjust LED footprint to T1 standard
    update plates and traces
    [keyboard.kicad_pcb, layout.FCStd, left-keyboard.step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]
2023-10-24 add copper fill to plates and correct plate silkscreen
    [left-keyboard.step, plate.kicad_pcb]
2023-10-24 plot gerbers and improve ground trace
    [keyboard.kicad_pcb]
2023-10-24 correct silkscreen for TRRS jack; add spreadsheet for component ordering
    [components.ods, keyboard.kicad_pcb]
2023-10-25 fix LED footprints; with radius and centreing
    [keyboard.kicad_pcb, plate.kicad_pcb]
2023-10-25 fix schematic of LED pins
    [keyboard.kicad_pcb, keyboard.kicad_sch]
2023-10-25 improve traces around microcontroller
    [components.ods, keyboard.kicad_pcb]
2023-10-26 suggest more stuff to order
    [components.ods]
2023-10-26 start working on pinky separation; update layout and move some footprints
    [keyboard.kicad_pcb, layout.FCStd]
2023-10-27 improve switch double pads
    [keyboard.kicad_pcb, keyboard.kicad_sch]
2023-10-27 move pinky up by 1mm
    [keyboard.kicad_pcb, layout.FCStd]
2023-10-27 update plates with asymmetrical pinky stagger
    [left-keyboard.step, plate.kicad_pcb, plate.kicad_sch]
2023-10-27 update toggling 3D model for left and right sides
    [keyboard.kicad_pcb, keyboard.kicad_sch]
2023-10-27 fix DRC footprint type mismatch
    [keyboard.kicad_pcb]
2023-10-27 fix silkscreen for double switch
    [keyboard.kicad_pcb]
2023-10-29 fix teardrops with taps
    [keyboard.kicad_pcb]
2023-10-29 fix minimum silkscreen width
    [keyboard.kicad_pcb]
2023-10-29 fix LED footprint name and type
    [keyboard.kicad_pcb, keyboard.kicad_sch]
2023-10-29 reduce breakoff gap to 1mm
    [keyboard.kicad_pcb, layout.FCStd, left-keyboard.step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]
2023-10-30 use edge cuts for overlapping drill holes
    adjust pads to 0.3mm clearance
    [keyboard.kicad_pcb, plate.kicad_pcb]
2023-10-30 rerun rezone
    [keyboard.kicad_pcb]
2023-10-30 add 0.001mm to clearance in curved pads and fix breakoff fill exclusion
    [keyboard.kicad_pcb]
2023-10-30 remove silkscreen from right plate
    [left-keyboard.step, plate.kicad_pcb]
2023-10-30 change plates to 1.2mm
    [left-keyboard.step, plate.kicad_pcb]
2023-10-31 rework footprints with 3d models
    [keyboard.kicad_pcb, keyboard.kicad_sch]
2023-10-31 move 3d footprints into position
    [keyboard.kicad_pcb, keyboard.kicad_sch]
2023-10-31 change plate colours to charcoal
    [left-keyboard.step]
2023-11-02 start writing readme
    [components.ods]
2023-11-02 add layout part in readme; add HL and HR in export script; add page details in pcb
    [keyboard.kicad_pcb]
2023-11-02 write KiCad readme; fix colour of left plate
    [left-keyboard.step]
2023-11-02 document plugins; fix layout label
    [layout.FCStd]
2023-11-20 update readme with pcb photo
2023-11-25 add post-boot LED blink
2023-12-07 add controller-plate
    [controller-plate.step, keyboard.kicad_pcb, keyboard.kicad_sch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]
